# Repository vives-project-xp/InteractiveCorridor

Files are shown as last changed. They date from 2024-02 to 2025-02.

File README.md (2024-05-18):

# Interactive Corridor

Welcome to the Interactive Corridor Project! This unique corridor is designed to create depth and atmosphere through innovative lighting effects. With a variety of pre-programmed light patterns and the ability to design your own, you can transform the corridor into a dynamic and immersive space.

Controlling the effects is simple, just use the web interface hosted on a central server to customize the lighting. Whether you're aiming for subtle transitions or dramatic transformations, the Interactive Corridor Project gives you the tools to set the perfect mood. Enjoy exploring the endless possibilities!

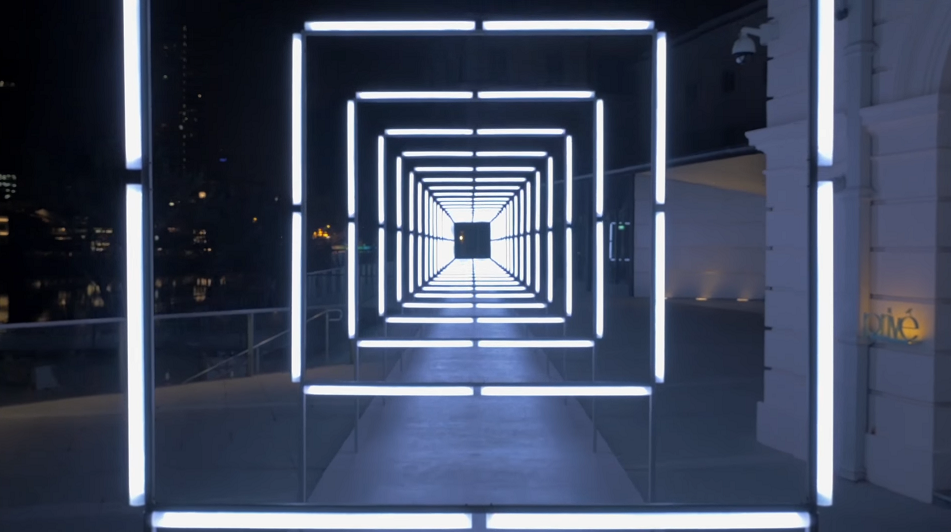
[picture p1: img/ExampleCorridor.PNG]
ExampleCorridor

The project is based on a video of the River Nights Festival (Singapore) where there was a beautiful light setup.
<https://www.youtube.com/watch?v=xEEKBbKvuMQ>

## The Team

[ Robbe De Wispelaere](https://github.com/RobbeDeW)

[ Aitor Vannevel](https://github.com/imawizzard)

[ Simon Stijnen](https://github.com/SimonStnn)

[ Niels Denoo](https://github.com/NielsDenoo)

## The idea

- **Dynamic Light Patterns** : Create customizable lighting sequences that can change in intensity, color, and direction to generate a sense of movement and depth within the corridor.
- **User-Friendly Web Interface**: Design an intuitive web page where users can easily control and customize the corridor's lighting effects. The interface should allow for real-time adjustments, offer a library of pre-set themes, and provide options to create and save custom patterns for future use.
- **MQTT Communication**: Use MQTT (Message Queuing Telemetry Transport) to send commands from the web interface to the LED strips. This lightweight messaging protocol ensures fast and reliable communication, allowing for seamless updates to the light patterns.
- **WLED Integration**: Implement WLED, an open-source control system for LED strips, to manage the lighting effects in the corridor. WLED allows for a wide range of customization options and can be controlled remotely, making it a perfect fit for this project.

## Folder Structure

- [Website](website/README.md): All information about how the website works and how the user can interact with it.
- [Backend](Backend/README.md) All information about how the website communicates with the ledstip's.
- [Docs](docs/README.md): All information about the hardware and setup

## Corridor data flow diagram

<picture>
  <source
    srcset="docs/exports/SoftwareArchitectureDiagram_dark.svg"
    media="(prefers-color-scheme: dark)"
  />
  <source
    srcset="docs/exports/SoftwareArchitectureDiagram_light.svg"
    media="(prefers-color-scheme: light), (prefers-color-scheme: no-preference)"
  />
  
</picture>

### Input requirements

The input requirements for the project are:

- The user should be able to control the LED strips via a web interface.
- The user should be able to change the color and brightness of the LED strips.
- The user should be able to select different lighting effects and animations for the LED strips.

### Functional requirements

The functional requirements for the project are:

- The system should provide a web interface for the user to control the LED strips.
- The system should provide an API for the web interface to communicate with the server.
- The server should listen to the API and control the ESP32s via the [WLED MQTT interface](https://kno.wled.ge/interfaces/mqtt/).
- The system should provide a user-friendly interface to adjust the color, brightness, and lighting effects of the LED strips.
- The system should provide a variety of lighting effects and animations for the user to choose from.
- The system should be able to handle multiple ESP32s.
- The system should be able to handle multiple users controlling the LED strips simultaneously.

### Output requirements

The output requirements for the project are:

- No flickering or lag in the LED strips.
- Reaction time is below 100ms.

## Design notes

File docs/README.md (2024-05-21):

# Documentation

Welcome to the documentation page! This is your go-to resource for understanding everything about our hardware system, including a detailed breakdown of the components we use. Whether you're building your own setup or simply exploring the technology, this page aims to provide all the information you need.

## Table of contents

- [Documentation](#documentation)
  - [Table of contents](#table-of-contents)
  - [Installation](#installation)
  - [Bill of Materials](#bill-of-materials)
  - [Level shifter](#level-shifter)
  - [Architecture documents](#architecture-documents)
    - [Hardware architecture diagram](#hardware-architecture-diagram)
    - [Wiring architecture diagram](#wiring-architecture-diagram)
    - [Wiring for Level shifter](#wiring-for-level-shifter)
  - [ESP Pinout](#esp-pinout)
  - [Measurements](#measurements)

## Installation

The installation of the hardware is quite simple. You can follow the steps below to install the hardware system:

1. **Mount the ledstrips**: Mount the ledstrips on the pillars. Mounting can be found in [mounting](./mounting/). You will also learn more about the process.
2. **Setup the ESP**: Setup the ESP32-C3. Installation steps can be found [here](./ESP_SETUP.md).
3. **Run the backend**: Run the backend. Installation steps can be found [here](../Backend/README.md#installation).

## Bill of Materials

These are the components that we purchased. You of course have different websites to purchase this, but we mainly looked at the price and quality of the product.

The Bill of Materials (BOM) lists all the components, parts, and materials needed for one corridor consisting of 6 pillars:

| Component | Quantity | Price / unit |
| :--- | :---: | ---: |
| [**ws2814-rgbw-led-strip**](https://www.btf-lighting.com/products/ws2814-12v-24v-4-in-1-similar-sk6812-rgbw-pixels-addressable-ws2811-rgbww-rgbcw-5050-3pin-led-lights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) | 6 | €22,35 |
| [**esp32-c3**](https://www.digikey.be/en/products/detail/espressif-systems/ESP32-C3-DEVKITM-1/13684315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) | 6 | €8,8451 |
| [**ledstrip-profile**](https://www.ledshop-groenovatie.com/Aluminium-Profiel-LED-Strip-Opbouw-1,5m-Compleet-1) | 16 | €17,95 |
| [**dcdc-converter**](https://www.otronic.nl/nl/lm2596s-instelbare-step-down-4-40v-125-37v-met-onb.html) | 6 | €5,39 |
| [**prototype-printplate**](https://www.otronic.nl/nl/experimenteer-prototyping-printplaat-7x9cm-groen.html) | 6 | €1,25 |
| [**cable-box**](https://www.allekabels.be/lasdoos/22371/3914218/aansluitdoos.html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) | 6 | €1,59 |
| [**power-supply**](https://www.ledstripkoning.be/accessoires/adapters-12-en-24-volt/600w-24v-25a-professionele-voeding-voor-led-strips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) | 1 | €76,95 |
| [**block-terminal**](https://be.farnell.com/camdenboss/ctb0100-6/pcb-terminal-5mm-6p/dp/3378876) | 6 | €2,12 |
| [**fuse-holder**](https://www.allekabels.be/zekeringen/1615/5715/standaard-zekeringhouder.html?lang=nl-be) | 3 | €4,22 |
| [**autofuse-set-10a**](https://www.allekabels.be/zekeringen/1615/1067905/mini-autozekering-10-ampere.html) | 1 | €5,29 |
| [**cables**](https://netstore.rexel.be/NS/servlet/be.rex.ns.cf.RexStartServlet?sessionreset=1) | 1 | €36,30 |
| [**female-pin-header-set**](https://be.farnell.com/en-BE/harwin/m20-7822046/connector-receptacle-tht-2-54mm/dp/7991967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) | 10 | €19,8 |
| [**Male-pin-header-set**](https://be.farnell.com/harwin/m20-9990846/connector-header-tht-2-54mm-8way/dp/1022257) | 10 | €3,52 |
| [**Lusterklemmen**](https://www.hubo.be/nl/p/profile-lusterklem-6mm-pvc-4-stuks/98445/) | 1 | €4,59 |

## Level shifter

| Component | Quantity | Price / unit |
| :--- | :---: | ---: |
| [**Resistor1K**](https://www.otronic.nl/nl/10x-weerstand-1k-ohm-1-4-watt-5.html) | 5 | €0,49 |
| [**Resistor1,5K**](https://www.kiwi-electronics.com/nl/weerstand-1-5k-ohm-1-4-watt-5-10-stuks-657) | 2 | €1,00 |
| [**transistor**](https://be.farnell.com/on-semiconductor/bc547ctfr/transistor-bipol-npn-45v-to-92/dp/2453792?st=BC547CTFR) | 24 | €6,312 |
| [**capacity1nF**](https://gigatek.be/nl/velleman-keramische-condensator-1nf--velvec1n0) | 24 | €0,08 |

## Architecture documents

### Hardware architecture diagram

<picture>
  <source
    srcset="./exports/HardwareArchitectureDiagram_dark.svg"
    media="(prefers-color-scheme: dark)"
  />
  <source
    srcset="./exports/HardwareArchitectureDiagram_light.svg"
    media="(prefers-color-scheme: light), (prefers-color-scheme: no-preference)"
  />
  
</picture>

The [architecture diagram](./ArchitectureDiagram.drawio) can be visualized in [app.diagrams.net](https://app.diagrams.net/) or with the [Draw.io Integration](https://marketplace.visualstudio.com/items?itemName=hediet.vscode-drawio) vscode extension.

If we look at the datasheets of all components, we need 2 different voltages.

- 24V for the ledstip
- 5V for the data and esp

### Wiring architecture diagram

<picture>
  <source
    srcset="./exports/Wiring-Wiring.drawio_Dark.svg"
    media="(prefers-color-scheme: dark)"
  />
  <source
    srcset="./exports/Wiring-Wiring.drawio_Light.svg"
    media="(prefers-color-scheme: light), (prefers-color-scheme: no-preference)"
  />
  
</picture>

### Wiring for Level shifter

<picture>
  <source
    srcset="./exports/Wiring-Level-Shifter.drawio_Dark.svg"
    media="(prefers-color-scheme: dark)"
  />
  <source
    srcset="./exports/Wiring-Level-Shifter.drawio_Light.svg"
    media="(prefers-color-scheme: light), (prefers-color-scheme: no-preference)"
  />
  
</picture>

The [architecture diagram](./ArchitectureDiagram.drawio) can be visualized in [app.diagrams.net](https://app.diagrams.net/) or with the [Draw.io Integration](https://marketplace.visualstudio.com/items?itemName=hediet.vscode-drawio) vscode extension.

## ESP Pinout

|  Pin  | Description |
| :---: | --- |
| GPIO1 | Ledstrip 1  |
| GPIO3 | Ledstrip 2  |

## Measurements

We have scope images of the level shifter, illustrating how the ESP (depicted in yellow) sends a 3.3V data signal. As it traverses the level shifter (represented by the blue signal), it is boosted to 5V. The green signal, measured at the collector of the first transistor, demonstrates signal inversion, necessitating the use of a second transistor.

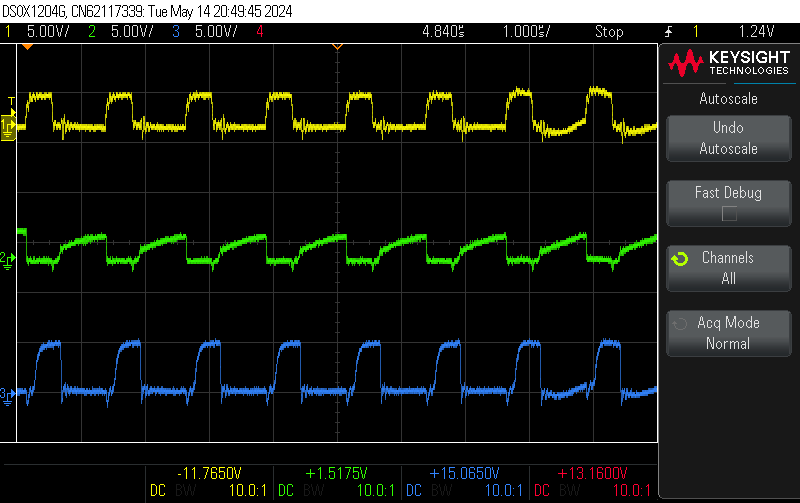
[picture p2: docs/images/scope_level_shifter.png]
Level Shifter


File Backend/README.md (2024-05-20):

# Backend

The backend is responsible for managing the ledstrips and the MQTT communication. It is implemented in JavaScript using [Node.js](https://nodejs.org/) and the [Express framework](https://expressjs.com/).

If you want to know more about the backend requests, click [here](http://10.11.0.100:9002/api-docs/). This link takes you to a swagger page where everything is explained.You must be connected to the Devbit network for this.

## Setup

First clone the repository:

```bash
git clone https://github.com/vives-project-xp/InteractiveCorridor.git
```

Setup your environment variables:

```bash
cp .env-example .env
```

Fill in the environment variables in the `.env` file.

Start the backend:

```bash
docker-compose up -d
```

The backend is now served on the URL specified in the `.env` file.

## UML Diagrams

```mermaid
classDiagram

class Segment {
    -start: number
    -end: number
    -color: Color
    -effect: Effect
    +constructor(parent: VirtualLedstrip, start: number, end: number, color: Color)
    +get length(): number
    +getHex(): string
    +setStart(start: number)
    +setEnd(end: number)
    +setColor(color: Color)
}

class Color {
    <<interface>>
    +r: number
    +g: number
    +b: number
}

class Effect {
    <<interface>>
    +id: number,
    +delay: number,
    +speed: number,
    +intensity: number,
    +reverse: bool,
    +mirror: bool,
}

class VirtualLedstrip{
    -_name: string
    -_segments: Segment[]
    +index: number
    +mqtt_enabled: boolean
    +get name: string
    +get segments: Segment[]
    +get length: number
    +constructor(name: string, index: number, segments: number[], mqtt_enabled: boolean)
}

VirtualLedstrip "1" *--o "1.." Segment
Color "1.." --* Segment
Effect "1.." --* Segment
```

## Virtual Ledstrip

The Virtual Ledstrip is a class that represents a ledstrip. It has a name, an index, a list of segments and a flag to enable or disable the MQTT communication.

### Constructor

The constructor of the Virtual Ledstrip class receives the following parameters:

- `name`: The name of the ledstrip.
- `index`: The index of the ledstrip.
- `segments`: An array of numbers representing the segments of the ledstrip.
- `mqtt_enabled`: A boolean flag to enable or disable the MQTT communication.

### Attributes

- `_name`: The name of the ledstrip.
- `_segments`: An array of segments.
- `index`: The index of the ledstrip.
- `mqtt_enabled`: A boolean flag to enable or disable the MQTT communication.

### Properties

- `name`: The name of the ledstrip.
- `segments`: An array of segments.
- `length`: The length of the ledstrip.

### Methods

The Virtual Ledstrip class has no methods.

## Segment

The Segment class represents a segment of a ledstrip. It has a start, an end and a color.

### Constructor

The constructor of the Segment class receives the following parameters:

- `start`: The start of the segment.
- `end`: The end of the segment.
- `color`: The color of the segment.

### Attributes

- `start`: The start of the segment.
- `end`: The end of the segment.
- `color`: The color of the segment.

### Properties

- `length`: The length of the segment.

### Methods

- `getHex()`: Returns the color of the segment in hexadecimal format.
- `setStart(start)`: Sets the start of the segment.
- `setEnd(end)`: Sets the end of the segment.
- `setColor(color)`: Sets the color of the segment.

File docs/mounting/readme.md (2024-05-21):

# SETUP

> Ensure a well-organized setup where the LED strips are securely fastened and everything is neatly concealed.

### Discussion with Technical Service (21/02/24)

The technical service is considering providing power in the cable tray that crosses corridor B. We will provide an adapter that converts 220V to 24V. This will be installed in room B303, in the ceiling near the projector. The technical service will install a cable tray at the top of the corridor up to the first concrete pillar. We will supply aluminum brackets for the LED strip, which the technical service will then attach (drilling/adhesion).

We will handle the finishing touches:

- Box for the ESPs
- Brackets for the LED strips
- Wiring concealment

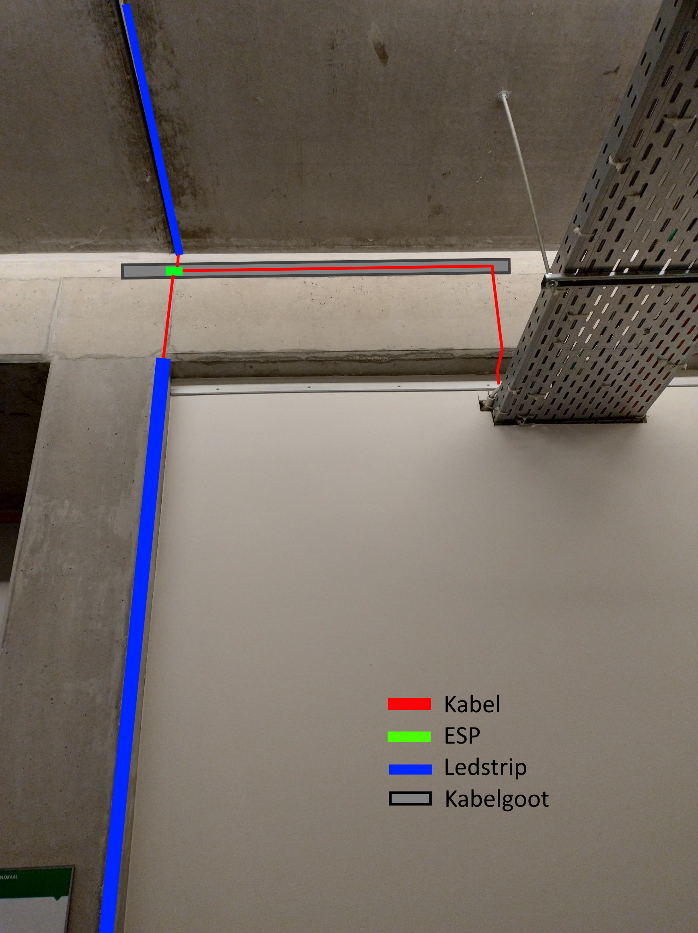
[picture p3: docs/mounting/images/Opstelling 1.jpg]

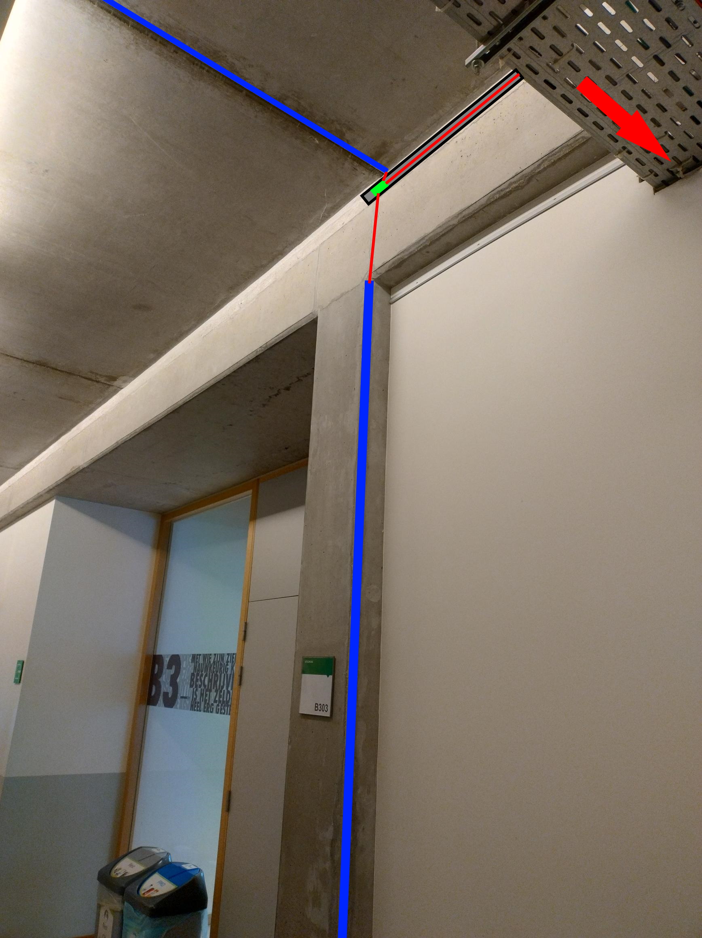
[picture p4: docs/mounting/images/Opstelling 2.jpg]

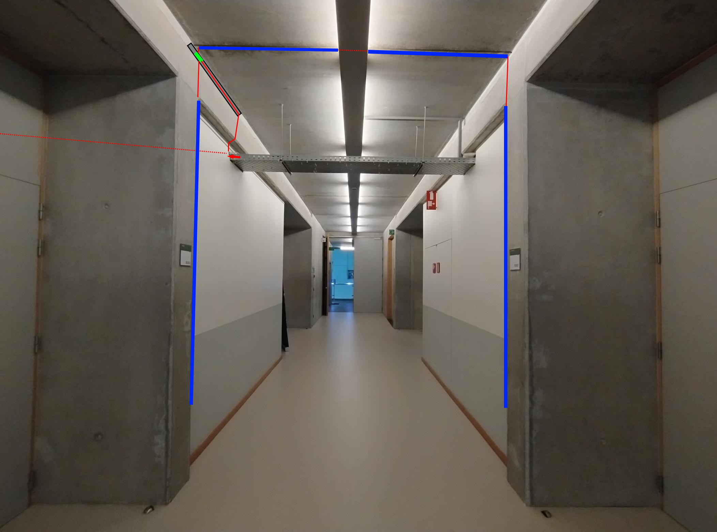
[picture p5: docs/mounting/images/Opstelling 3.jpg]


### First Corridor (22/04/2024)
To reduce costs, we have shortened the length of the defusers on the wall and they are now all 1m.

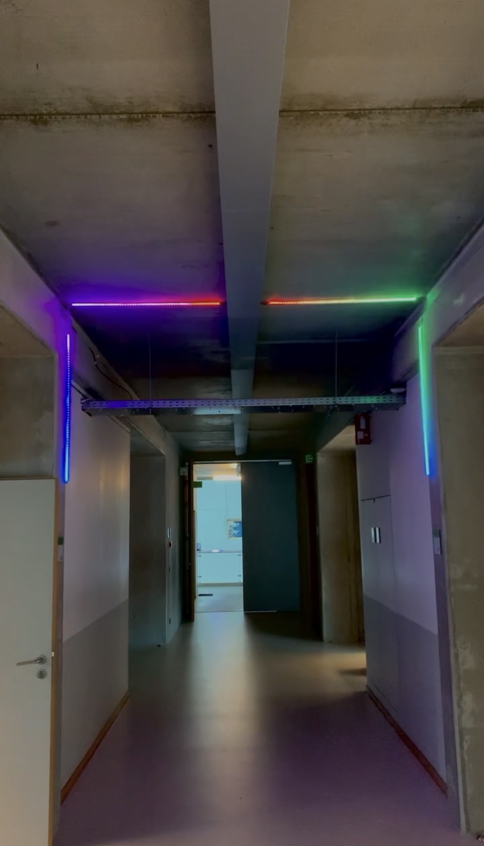
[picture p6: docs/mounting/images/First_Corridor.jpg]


### Final Result (14/05/2024)
This is the complete setup that you can control and we are very proud of this.😊

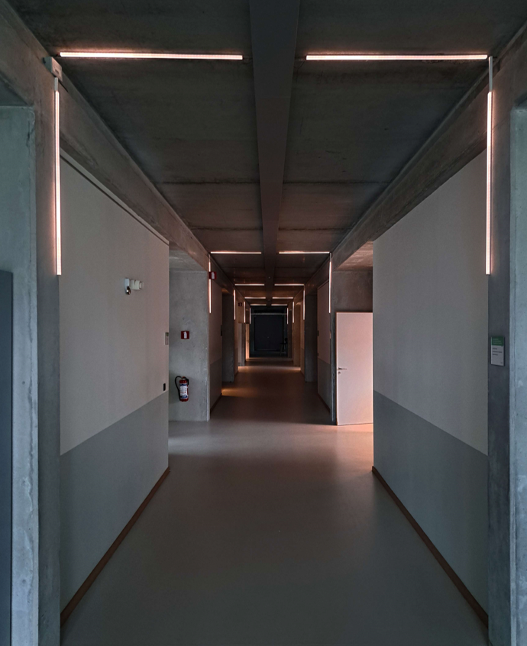
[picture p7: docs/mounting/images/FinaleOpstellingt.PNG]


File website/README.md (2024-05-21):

# Welcome to the "Website" page

This website is utilized to manage all corridors, thereby creating stunning effects in the hallway. [Website](http://10.11.0.100:9002/api-docs/) You must be connected to the Devbit network to access the website or you can do this yourself via Docker Desktop.

## Technologies used

- [Axios-HTTP](https://axios-http.com/): a promise based HTTP client for the browser and node.js
- [Tailwind CSS](https://tailwindcss.com/): a utility-first CSS framework
- [Shadcn-vue](https://www.shadcn-vue.com/): a component library for vue
- [Vue.js](https://vuejs.org/): a JavaScript framework for building user interfaces
- [Docker](https://www.docker.com/): a platform for building, shipping, and running applications in containers

## Home page

The main page serves as the central hub for customizing the aesthetic appeal of your corridors. It offers a user-friendly interface to effortlessly alter the colors of different segments according to your preferences. Each segment can be individually tailored with just a click. Simply choose the segment you wish to modify, and watch it transform before your eyes as you select your preferred color scheme.

But customization doesn't stop there. Want to create a more dynamic layout? With the "split" button, you can easily divide the corridor into smaller sections, providing greater flexibility in design. Whether you prefer a uniform look or a segmented display, this feature empowers you to configure your space exactly as you envision it.

To streamline the customization process even further, the "all" option enables you to select the entire corridor at once. This eliminates the need to manually click on each segment, saving you time and effort. Whether you're fine-tuning the details or making sweeping changes, the main page offers intuitive tools to bring your corridor design to life with precision and ease

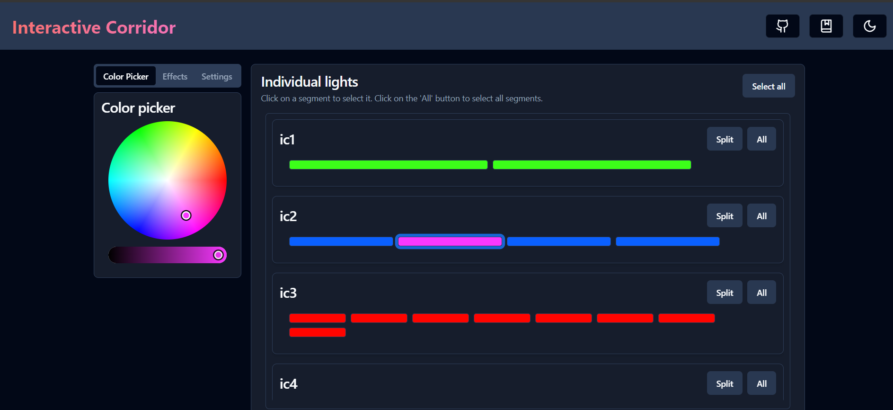
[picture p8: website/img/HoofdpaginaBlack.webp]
Home Page


## Effect page

### WLED effects

The effect page serves as a hub for enhancing the ambiance of your corridor with captivating visual effects. Similar to the color customization process, adjusting effects is seamless and intuitive. Simply select the segment or segments you wish to modify, and then choose from a diverse array of effects. From subtle pulsations to vibrant rainbows and beyond, there's a wide selection to suit every mood and theme.

What's exciting about these effects is their dynamic nature. Unlike color changes, the effects won't immediately manifest on your website interface. Instead, you'll need to hover over the segment to see what te effect is on that segment.

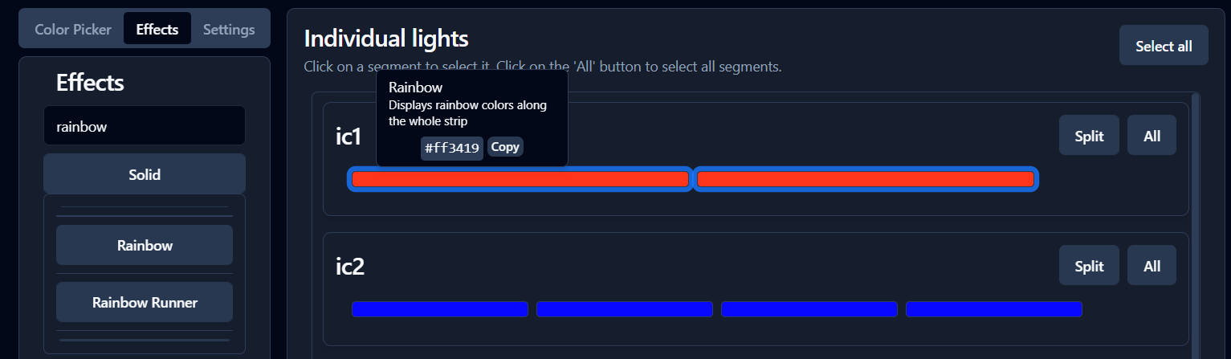
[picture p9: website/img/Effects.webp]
Effect page


### Own effects

Unlock your creativity by crafting and saving your own unique effects to imbue your corridors with a personalized touch. Whether it's experimenting with vibrant colors or layering mesmerizing effects, the possibilities are endless. Once you've perfected your creation, simply assign it a distinct name and save it for future use.

Choosing a descriptive and exclusive name for your custom effect is essential, as duplicate names are not permitted. This ensures that each effect in your repertoire is easily identifiable and avoids confusion when managing your collection. By meticulously naming your effects, you pave the way for seamless organization and effortless access to your favorite creations.

The ability to save custom effects streamlines your workflow, allowing you to effortlessly apply and replay intricate designs without starting from scratch each time. Whether you're refining existing effects or inventing entirely new ones, this feature empowers you to curate a library of personalized enhancements tailored to your unique vision.

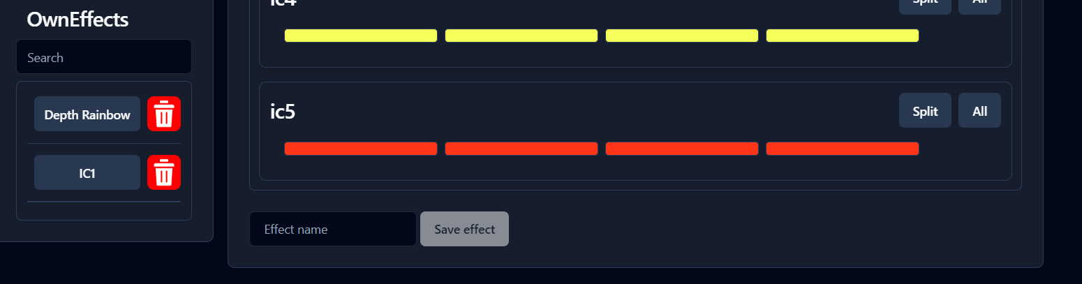
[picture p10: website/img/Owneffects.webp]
Own effects


## Settings page

- **Speed**: When you change the speed of an effect, the playback speed will be faster or slower.
- **Intensity**: Specifically, the "Intensity" setting adjusts the density or frequency of the effect applied to the LED strip.
- **Delay**: By adjusting the delay you will create a delay between 2 or more corridors so that, for example, they will turn on alternately with the blink effect.
- **Reverse Delay**: If you want the delay to work in a mirrored order, click this button (instead of the last corridor turning on first, the first corridor will turn on first and then the rest).
- **Mirror**: When you select the "Mirrored" option, each corridor will display the effect in a mirrored fashion.
- **Reverse**: When you press this button the effect will be played in reverse, although your effect runs from left to right by default, it will now be reversed.

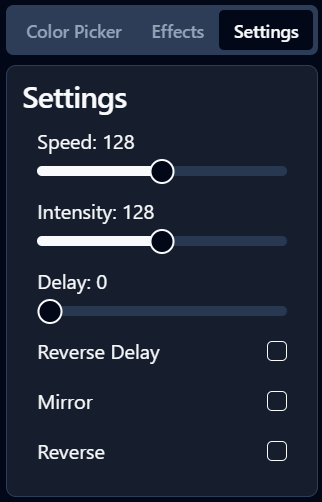
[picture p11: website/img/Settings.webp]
Settings


## Some extra's

As an added bonus, we've incorporated a delightful feature that allows you to effortlessly switch between light and dark themes for your website. Simply look to the top right corner of your screen, where you'll find an inviting sun and moon icon. By clicking on these icons, you can seamlessly transition between the two themes, catering to your preferred browsing experience.

Of course we have set dark theme as default 😉

You can also go to our GitHub page and documentation page when you press the buttons at the top right of the screen.

but here is an example of the white theme:
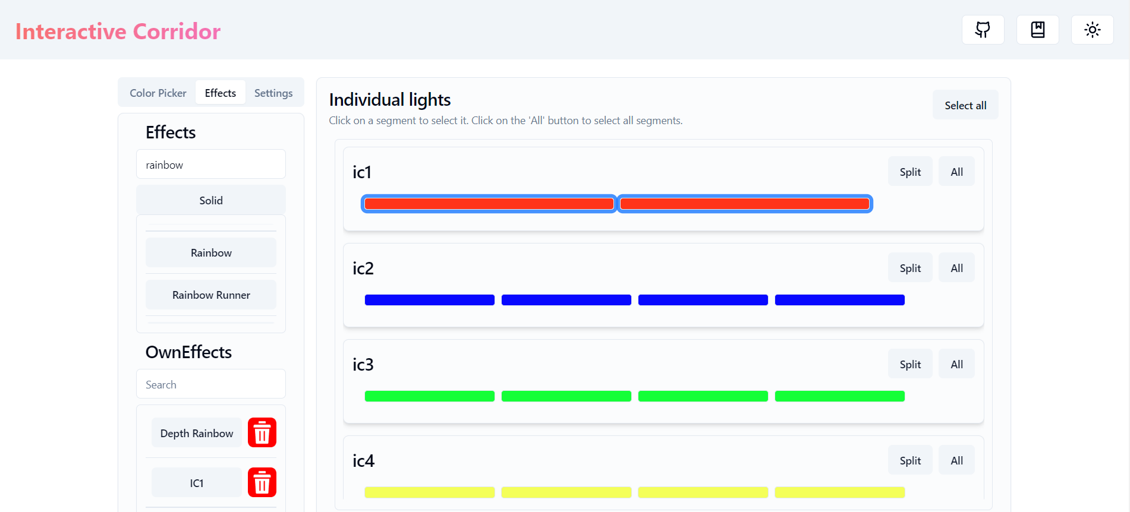
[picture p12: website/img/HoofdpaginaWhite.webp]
White team


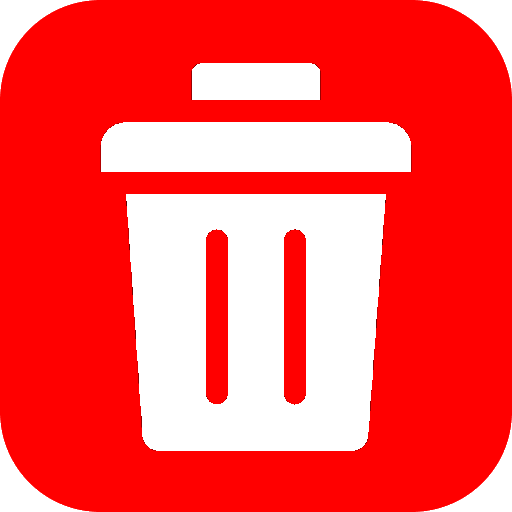
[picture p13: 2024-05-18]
website/img/delete.png

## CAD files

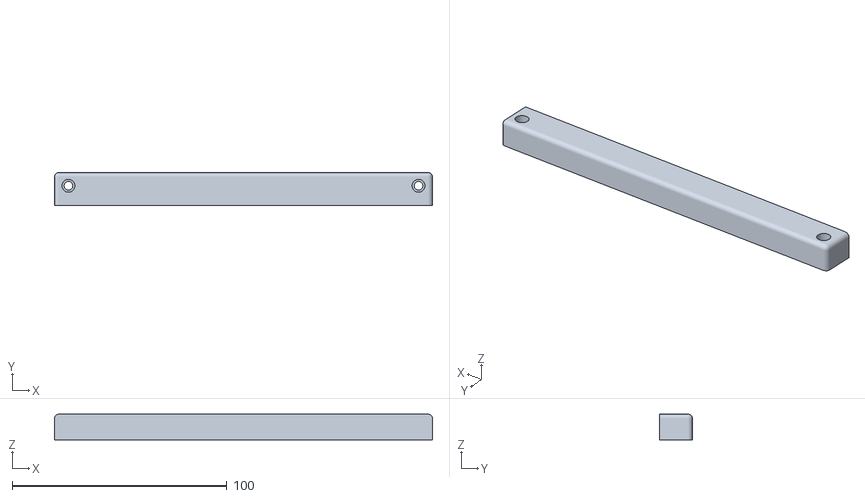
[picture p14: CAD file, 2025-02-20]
3dprints/SamsungTabA6Deksel.stl
176.0 x 15.3 x 12.0

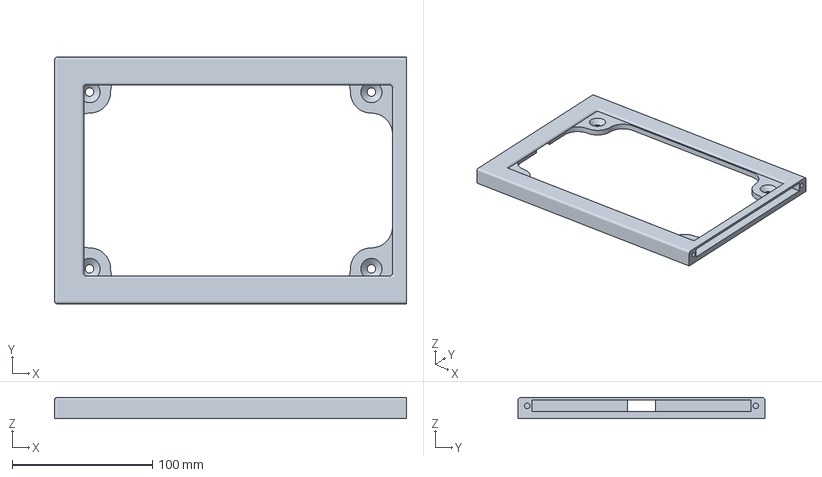
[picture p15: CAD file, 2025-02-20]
3dprints/SamsungTabA6.3mf
251.0 x 176.0 x 15.3 mm

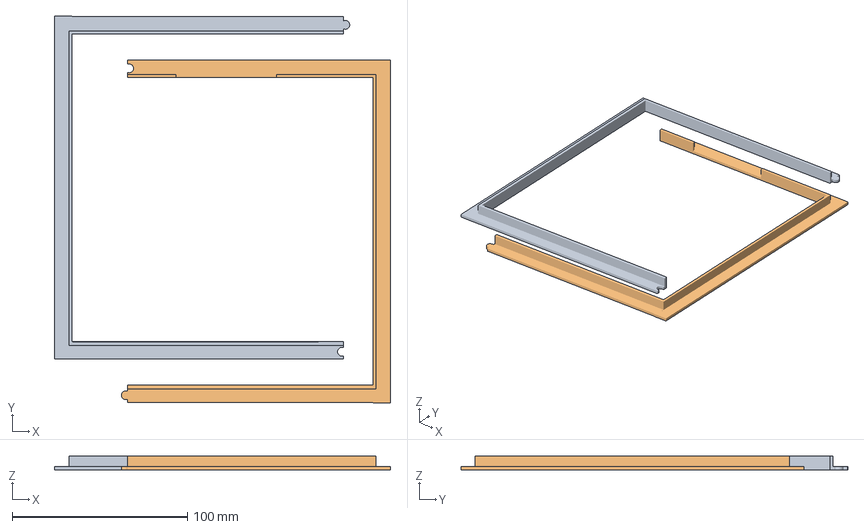
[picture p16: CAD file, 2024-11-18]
3dprints/SM-T580-Wandhalter_v2.3mf
191.6 x 220.6 x 8.26 mm
SM-T580-Abdeckungshalter.stl_1
SM-T580-Abdeckungshalter.stl_2

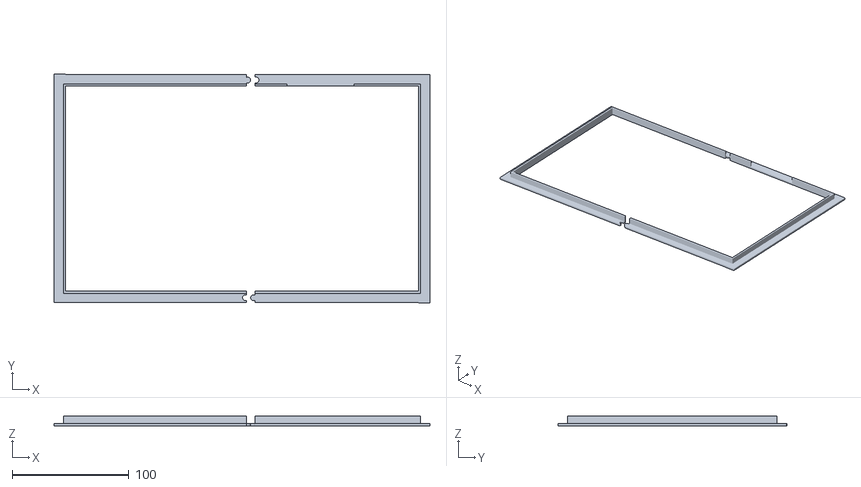
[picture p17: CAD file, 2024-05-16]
3dprints/SM-T580-Abdeckungshalter.stl
321.9 x 195.8 x 8.26

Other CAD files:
3dprints/SM-T580-Wandhalter_v2.stl
3dprints/SamsungTabA6.stl

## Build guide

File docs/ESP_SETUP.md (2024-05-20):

# Installing WLED on your ESP32

## Instructions

1. [Install WLED](#1-install-wled)
2. [Upload config file](#2-upload-config-file)
   - [2.1 Download the config file](#21-download-the-config-file)
   - [2.2 Upload the config file](#22-upload-the-config-file)
     - [2.2.1 Open the settings in WLED](#221-open-the-settings-in-wled)
     - [2.2.2 Open "Security & Updates"](#222-open-security--updates)
     - [2.2.3 Upload the config file](#223-upload-the-config-file)
3. [Reboot WLED](#3-reboot-wled)
4. [Setup MQTT](#4-setup-mqtt)
   - [4.1 Open the config](#41-open-the-config)
   - [4.2 Open Sync Interfaces](#42-open-sync-interfaces)
   - [4.3 Change settings](#43-change-settings)
   - [4.4 Reboot WLED](#44-reboot-wled)

## 1. Install wled

> Follow the instructions on the wled site to install wled on your device.

### **[Wled](https://install.wled.me/)**

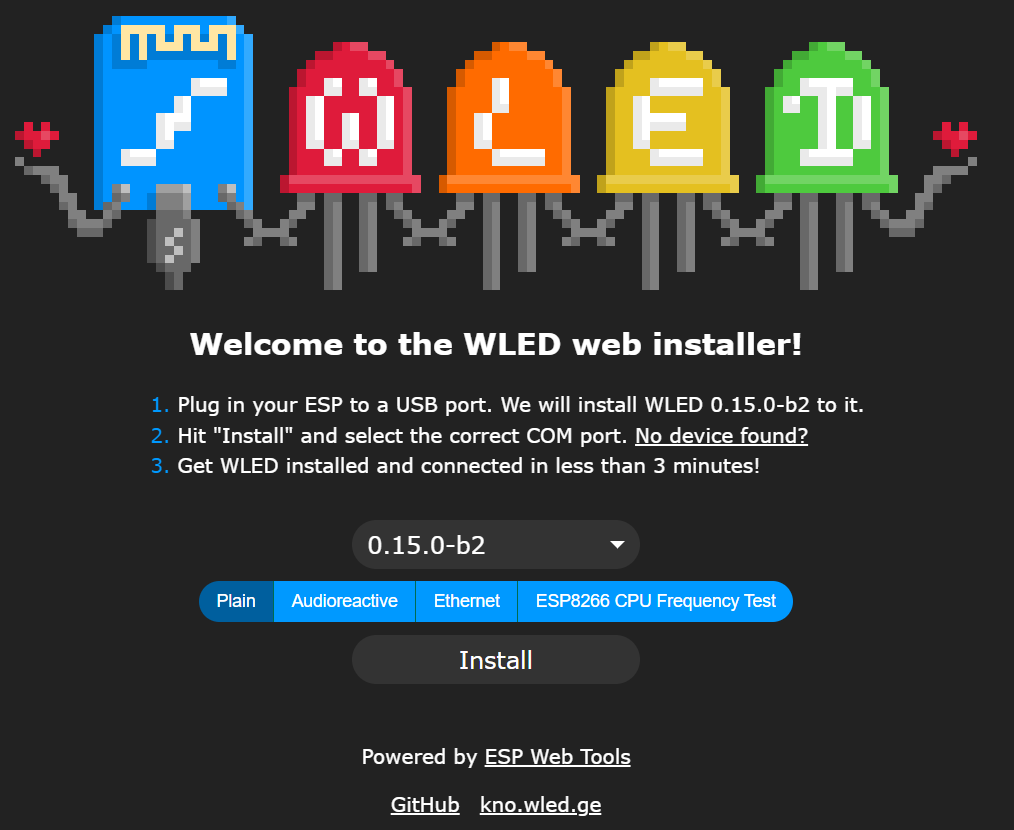
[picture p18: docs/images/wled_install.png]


## 2. Upload config file

### 2.1 Download the config file

You can download the config file <u>**[HERE](../wled_cfg.json)**</u>.

### 2.2 Upload the config file

> 2.2.1 Open the settings in wled.

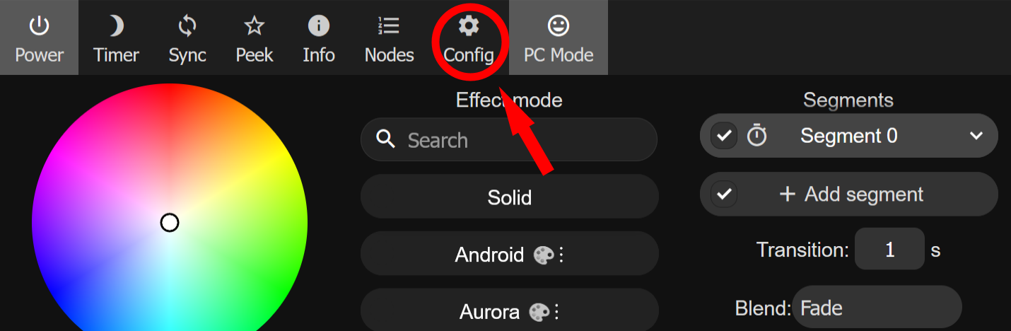
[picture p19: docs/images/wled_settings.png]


<br>
<br>

> 2.2.2 Open "Security & Updates".

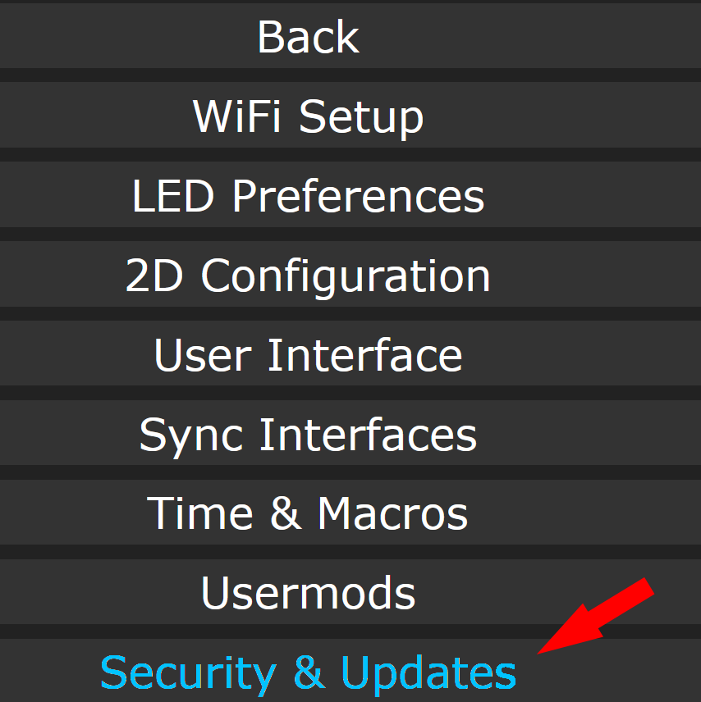
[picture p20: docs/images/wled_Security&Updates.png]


<br>
<br>

> 2.2.3 Upload the config file.

_Don't forget the save after upload!_
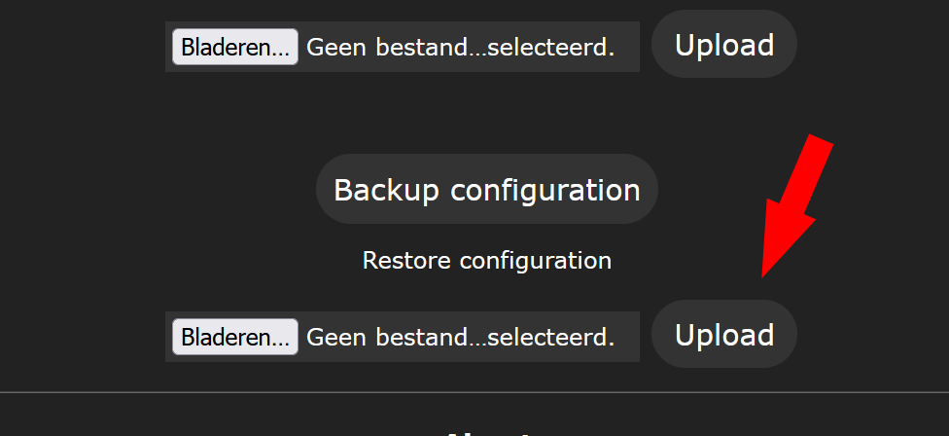
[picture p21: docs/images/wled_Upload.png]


## 3. Reboot wled

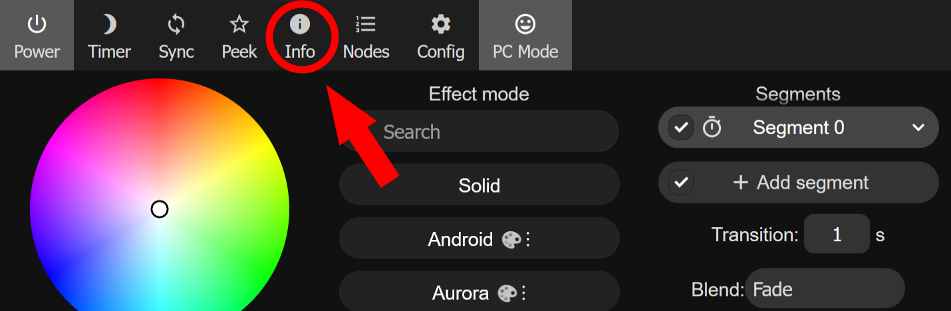
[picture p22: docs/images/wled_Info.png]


<br>

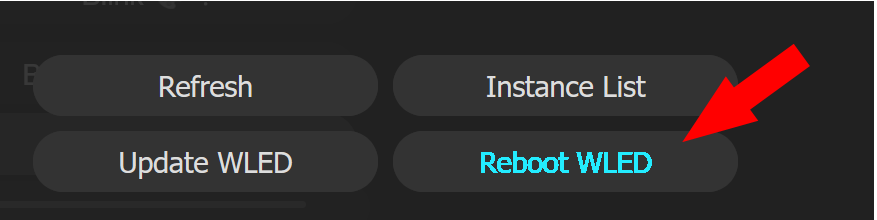
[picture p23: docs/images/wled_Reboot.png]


## 4. Setup mqtt

### 4.1 Open the config



### 4.2 Open Sync Interfaces

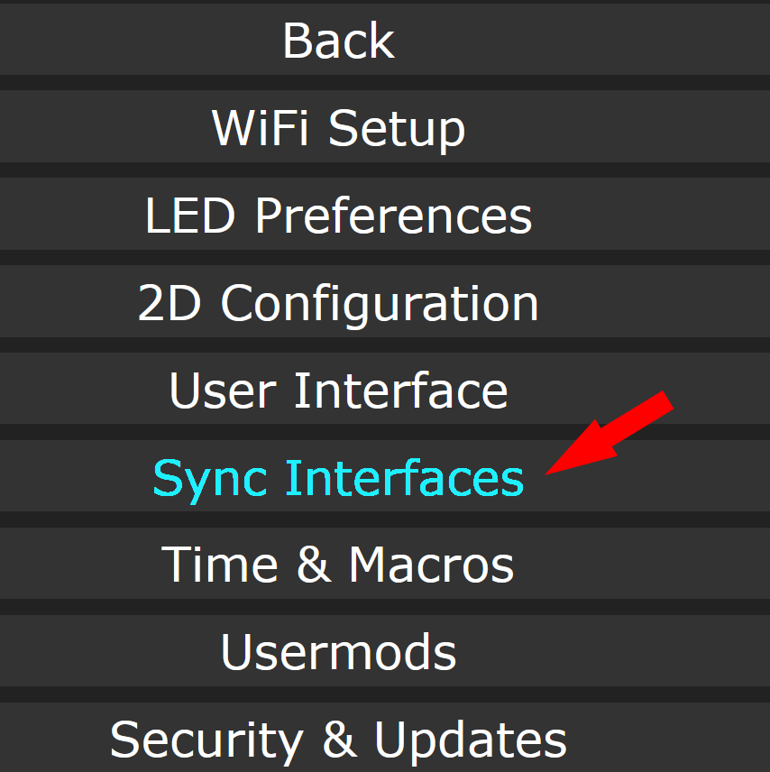
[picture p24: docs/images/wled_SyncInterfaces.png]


### 4.3 Change settings

> Fill in your broker url and login.
> Device & group topic is the topic you entered in the env file

#### **AFTER YOUR TOPIC, YOU NEED TO ADD /ic[LED_NUMBER]**

#### **THE GROUP TOPIC SHOULD END WITH /ALL**

_Don't forget the save after changing the settings!_

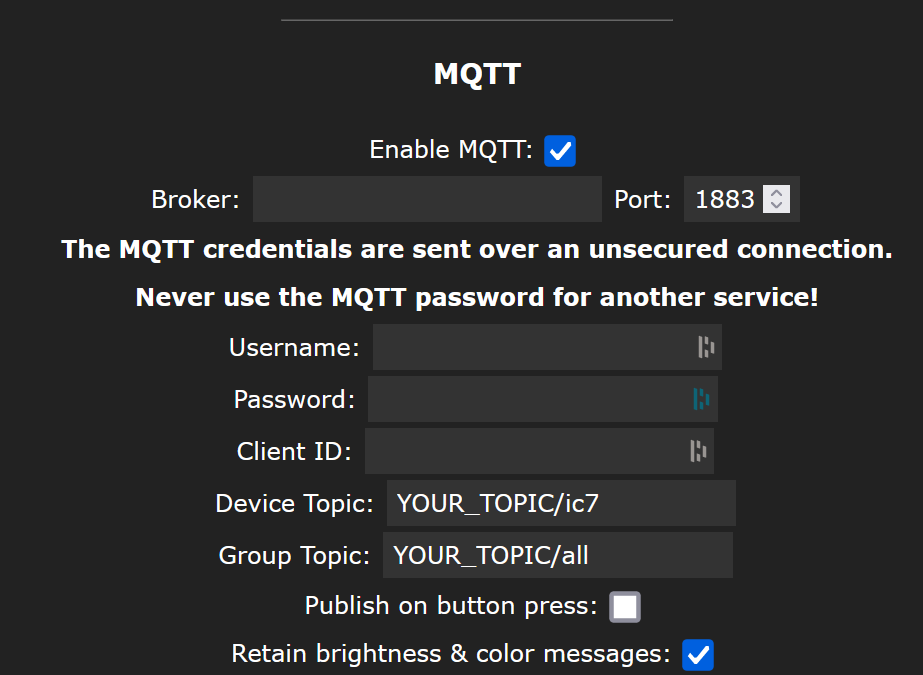
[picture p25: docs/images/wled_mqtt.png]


### 4.4 Reboot wled

Reboot wled one more time to load all the settings (see [3.Reboot wled](#3-reboot-wled)).

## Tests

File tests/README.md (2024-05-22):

# Tests

## Software

A list of tests that should be performed on the software. The software should be tested for the following:

<details>
<summary>Ease of use</summary>

- [x] An enduser should be able to use the software without any prior knowledge
  - [x] An enduser should be able to look and the website and know how to controll the ledstrips
  - [x] An enduser should be able to look at the website and know how to change the settings
  - [x] An enduser should be able to look at the website and know how to change the color of the ledstrips
  - [x] An enduser should be able to look at the website and know how to change the brightness of the ledstrips
  - [x] An enduser should be able to look at the website and know how to change the speed of the ledstrips
  - [x] An enduser should be able to look at the website and know how to change the mode of the ledstrips
  - [x] An enduser should be able to look at the website and know how to change the direction of the ledstrips
  - [x] An enduser should be able to look at the website and know how to split a ledstrip in multiple segments
  - [x] An enduser should be able to look at the website and know how to change the color of a segment
  - [x] An enduser should be able to look at the website and know how to change the color of a whole ledstrip
- [x] The software should be easy to install
  - [x] An step by step installation guide should be available
  - [x] Someone with basic knowledge of computers should be able to install the software
  - [x] After setting up the config files the software should be able to start with one command
- [x] The software should be easy to configure
  - [x] A step by step configuration guide should be available with with files to edit and what to edit

</details>

<details>
<summary>Documentation</summary>

- [x] The website should have a README.md file
  - [x] The README.md file should contain a description of the software
  - [x] The README.md file should contain the technologies used
  - [x] The README.md file should contain some screenshots of the website
- [x] The backend should have a README.md file
  - [x] The README.md file should contain a description of the software
  - [x] The README.md file should contain the technologies used
  - [x] The README.md file should contain an UML diagram of the Virtual Ledstrip
  - [x] The README.md file should contain documentation of the Virtual Ledstrip
- [x] There shoud be a docs folder with a README.md file
- [x] Swagger API docs
  - [x] The API should be documented with Swagger
  - [x] The Swagger docs should have the save paramters and responses as the API

</details>

## Hardware

<details>
<summary>Components</summary>

- [x] The converter should convert the 24V input into 5V output
- [x] The level shifter should be able to make the 3.3V signal into a 5V signal
- [x] The electrical supply should be able to power all the 5 ledstrips
- [x] Test the ledstrips
  - [x] Test the max current of the ledstrips
  - [x] Check the required voltage of the ledstrips
- [x] Test if the ESP sends a signal
- [x] Test if the ledstrips are working with the signal
  - [x] Check if the signal at the end is 5V
  - [x] Check if u get the right effect on the ledstrips
- [x] Test if everything works

</details>

<details>
<summary>Documentation</summary>

- [x] The signals of the hardware should be documented with scope images
- [x] The README.md file in docs should contain info about the used components
- [x] The README.md file in docs should contain both hardware and software architecture diagram
- [x] The README.md file in docs should contain wiring diagram and how the level-shifter is made

</details>

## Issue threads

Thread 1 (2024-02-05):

Meten hoogt een breedte gang

RobbeDeW, 2024-02-05:
De ledstips worden in de gang gehangen waardoor we de hoogte en de breedte van de gang moeten weten.

RobbeDeW, 2024-02-05:
Lengtes van de gang
Hoogt: 3.30m
Breedte: 2.40m

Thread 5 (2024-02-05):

Mail Sam Baldewijns

NielsDenoo, 2024-02-05:
Mail sturen naar Sam Baldewijns voor mogelijkheden elektriciteit voor ledstrips (eerst mail sturen naar meneer Leroy voor goedkeuring mail)

RobbeDeW, 2024-02-07:
Mail naar project begeleider verstuurt om te weten of het een goede mail was en we mogen afspreken met Sam.

RobbeDeW, 2024-02-19:
Mail naar Sam is verzonden.

RobbeDeW, 2024-02-19:
Er is een datum vastgelegd om af te spreken met Sam.

Closed 2024-02-19.

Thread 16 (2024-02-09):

General Product Architecture: Power

SimonStnn, 2024-02-09:
Describe how the ESP and LED strip will receive power in the docs.

SimonStnn, 2024-02-09:
## ESP32

ESP32 can be powered over USB with 5V or it can be powered via the pins with 3.3V as mentioned [here](https://docs.espressif.com/projects/esp-hardware-design-guidelines/en/latest/esp32c3/schematic-checklist.html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,no%20less%20than%20500%20mA.).

## LED strip

LED strip requires a 24V power supply

Closed 2024-03-04.

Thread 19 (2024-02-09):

Complete BOM table

SimonStnn, 2024-02-09:
Complete the table of the [BOM](https://github.com/vives-project-xp/InteractiveCorridor/tree/main/docs#bill-of-materials) with the components, items, materials, etc needed to build a corridor.

> This is the same list you made in #2

SimonStnn, 2024-02-09:
Install the [Markdown All in One](https://marketplace.visualstudio.com/items?itemName=yzhang.markdown-all-in-one) vscode extension so you can format the table when you want to commit (`Alt + Shift + F`).

Also install the [markdownlint](https://marketplace.visualstudio.com/items?itemName=DavidAnson.vscode-markdownlint) vscode extension. This will lint markdown files.

> Don't commit if you have warnings in the document 😉.

Closed 2024-02-27.

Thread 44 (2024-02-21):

Ontwerp website maken

RobbeDeW, 2024-02-21:
Een ontwerp maken voor de website. Dit wordt best eerst op papier in klad gedaan.
- Hoe ziet de website er uit
- Interactie met gebruiker en leds
- Pagina effecten, interactie,

SimonStnn, 2024-02-21:
Ontwerp kan met figma gemaakt worden. Die kunnen opgeslaan worden als .fig bestanden.

Closed 2024-02-28.

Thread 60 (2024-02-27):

Testen 24V Ledstip

RobbeDeW, 2024-02-27:
-Er worden metingen gedaan met deze ledstip
-Er wordt getest of de ledstip goed werkt

RobbeDeW, 2024-02-27:
Ledstip werkt zonder level shifter maar als we een level shifter gebruiken die in school aanwezig was werkt de ledstip niet meer.

imawizzard, 2024-03-11:
Met onze eigen levelshifter werken de ledstrips perfect. Er zijn geen verstoringen meer doordat de data nu op 5V wordt gestuurd.

Closed 2024-03-11.

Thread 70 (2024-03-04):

Issue when fetching ledstrips in server

SimonStnn, 2024-03-04:
When fetching the leds it fails and it responds it has found 0 strips.

Closed 2024-03-04.

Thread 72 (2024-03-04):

Warnings when creating leds on website

SimonStnn, 2024-03-04:
`undefined` gets passed in as a color, which is invalid.

```txt
Invalid prop: type check failed for prop "color". Expected String with value "undefined"
```

Closed 2024-03-04.

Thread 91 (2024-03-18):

Color picker color gets reset when switching tabs on website

SimonStnn, 2024-03-18:

Closed 2024-03-18.

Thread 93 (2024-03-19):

Something is wrong with the swagger ui version

SimonStnn, 2024-03-19:
Our current ui looks like this:
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

But it should look like this:
(example)
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

This propably has something to do with the version of swagger ui.

SimonStnn, 2024-03-19:
Problem can be fixed with [swagger-jsdoc](https://www.npmjs.com/package/swagger-jsdoc).

Closed 2024-03-19.

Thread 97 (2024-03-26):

Ledstrip section color gets reset after some delay

SimonStnn, 2024-03-26:

Closed 2024-03-30.

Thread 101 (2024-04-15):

Search secondary school to give the presentation

SimonStnn, 2024-04-15:
Go 21 april to KTA Brugge open day.

SimonStnn, 2024-04-15:
"Graag een selfie"

SimonStnn, 2024-04-22:
We mogen presentatie gaan geven, wel nog eens een mailtje sturen om verder af te spreken.

We can give a presentation, we can send an email to discuss further.

Closed 2024-04-22.

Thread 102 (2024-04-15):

Handle changing ledstrip effects

SimonStnn, 2024-04-15:
Send effects to the selected sections when clicking an effect

SimonStnn, 2024-04-16:
There is still an issue with updating the effect. (#108)

Closed 2024-04-16.

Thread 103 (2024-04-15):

Ledstip aan muur hangen

RobbeDeW, 2024-04-15:
We plakken met plakband de lestip aan de muur om te zien of dat er goed uit ziet en op welke manier we hem aan de muur zullen hangen.

RobbeDeW, 2024-04-16:
Het ziet er goed uit dus dit kan nu aan de muur worden gehangen

Closed 2024-04-16.

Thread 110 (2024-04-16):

Get own effect from database on website

RobbeDeW, 2024-04-16:
We halen alles effecten op vanuit de database en geven deze weer op de website inde vorm van een button. Als je of deze button drukt zou het effect moeten worden afgespeeld.

RobbeDeW, 2024-04-16:
Dit werkt je kunt je own effects zien op de website de knop werkt wel nog niet

Closed 2024-04-16.

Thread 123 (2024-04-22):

Kabel doortrekken

RobbeDeW, 2024-04-22:
We leggen een 2mm dikke kabel naar het lokaal om ons van stroom voorzien.

RobbeDeW, 2024-04-22:
De kabel is doorgetrokken en er kan nu vanuit het lokaal stoom genomen worden

Closed 2024-04-22.

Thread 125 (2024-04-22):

Ledstrip segmends don't get set by the server

SimonStnn, 2024-04-22:
The one segment preset doesn't get overridden when updating the strip

Closed 2024-04-23.

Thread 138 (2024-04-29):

Throttle the requests to change the effect

SimonStnn, 2024-04-29:
When setting the effect in the settings tab the requests should be throttled to prevent overloads.

Closed 2024-04-29.

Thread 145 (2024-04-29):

Fixing ledstip

RobbeDeW, 2024-04-29:
De ledstrip die niet werkt hersolderen

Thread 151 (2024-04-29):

Effect loading from db not correct

imawizzard, 2024-04-29:
The length of the segments are wrong when loading from the database

imawizzard, 2024-05-14:
Effect are now correct loading from the database.
Added delete button.

Closed 2024-05-14.

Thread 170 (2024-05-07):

Pop up name 'already exists' dB owneffects

RobbeDeW, 2024-05-07:
Als een gebruiker een nieuw effect wil opslaan en het een naam geeft, moet je ervoor zorgen dat deze naam niet al in de database voorkomt.

RobbeDeW, 2024-05-15:
Het pop up scherm werkt

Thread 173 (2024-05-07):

Error in ledstrip.vue

imawizzard, 2024-05-07:
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

imawizzard, 2024-05-07:
Wrong api call: /effect -> /effects

Closed 2024-05-07.

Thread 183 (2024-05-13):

Use permalink for effects

SimonStnn, 2024-05-13:
Change the source url for the effects to a permalink. If they change any of the effects our ledstrip will not break.

Use this link:
[`https://raw.githubusercontent.com/scottrbailey/WLED-Utils/ec0bad83b35358137569d4cc9a016e235e00ffed/effect_descriptions.json`](https://raw.githubusercontent.com/scottrbailey/WLED-Utils/ec0bad83b35358137569d4cc9a016e235e00ffed/effect_descriptions.json)

Replace the link here:
https://github.com/vives-project-xp/InteractiveCorridor/blob/13fde039942210312197d2efa013e76b2fd1a01d/Backend/src/effect.js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

Closed 2024-05-13.

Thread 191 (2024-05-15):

Write the website README

SimonStnn, 2024-05-15:
The README should contain the tests defined in the tests.

https://github.com/vives-project-xp/InteractiveCorridor/blob/cd700050d2d5e619b6452cdbe7e34032e2879e4b/tests/README.md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

RobbeDeW, 2024-05-15:
Alles over de hoe je de kleuren en over de effecten staat in de readme

Closed 2024-05-19.

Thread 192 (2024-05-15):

Presentatie updaten

RobbeDeW, 2024-05-15:
We hebben onze presentatie gedaan in de middelbare school deze moet nog worden geupdate voor onze eindpresentatie.

NielsDenoo, 2024-05-17:
Er is een sjabloon aangemaakt voor de presentatie die gebruikt moet worden voor de eindpresentatie

Closed 2024-05-22.

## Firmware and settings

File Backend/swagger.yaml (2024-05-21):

openapi: 3.0.8
info:
  title: Stripconfiguratie API
  description: API voor het configureren van LED-strips.
  version: 1.0.0
servers:
  - url: http://localhost/api
    description: Backend server # Beschrijving van de server

paths:
  /leds:
    get:
      summary: Get LED configurations
      responses:
        200:
          description: "Successful operation"
          content:
            application/json:
              schema:
                type: array
                items:
                  $ref: "#/components/schemas/Ledstrip"

    post:
      summary: Set LED configurations
      parameters:
        - in: query
          name: query
          required: true
          schema:
            type: array
            items:
              $ref: "#/components/schemas/Ledstrip"
      responses:
        200:
          description: LED configurations set successfully
  /changeled:
    post:
      summary: Change LED segments
      parameters:
        - in: query
          name: query
          required: true
          schema:
            type: object
            properties:
              strip:
                type: object
                properties:
                  index:
                    type: number
                    description: The index of the LED strip
      responses:
        200:
          description: LED segments changed successfully
  /effects:
    post:
      summary: Set effect for LED strips
      parameters:
        - in: query
          name: query
          required: true
          schema:
            type: object
            properties:
              strips:
                type: array
                items:
                  $ref: "#/components/schemas/Ledstrip"
              delay:
                type: number
                description: Delay for the effect
                minimum: 1
                maximum: 1000
                nullable: true
              effect:
                type: number
                description: ID of the effect
                example: 0
              intensity:
                type: number
                description: Intensity of the effect
                minimum: 1
                maximum: 255
                nullable: true
              mirror:
                type: boolean
                description: Mirror the effect
                nullable: true
              reverse:
                type: boolean
                description: Reverse the effect
                nullable: true
              reverseDelay:
                type: boolean
                description: Reverse the delay
                nullable: true
              speed:
                type: number
                description: Speed of the effect
                minimum: 1
                maximum: 255
                nullable: true
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

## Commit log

2024-02-05 Add hall dimensions to docs README.md
2024-02-05 Add server and ledstrip details to README.md
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2024-02-06 Move esp code from esp/LedControl/ to esp/
2024-02-07 created python script to sned mqtt messages to the ledstrips
2024-02-07 Add ESP32 and WLED software documentation
2024-02-09 Add power supply information for ESP32 and LED strips #16
2024-02-09 Add Bill of Materials template to README.md close #18
2024-02-10 Write WS2814 ledstrip interface documentation #17
2024-02-10 Update WS2814 LED strip information #17
2024-02-10 Update LED strip description #17
2024-02-10 Update WS2814 LED strip to WS2814 Protocol #17
2024-02-11 Remove unnecessary information about the ESP32 power handling #16
2024-02-11 Add WS2814 RGBW LED strip description
2024-02-19 Add shadcn button component
2024-02-19 Add esp32 to BOM #19
2024-02-19 Add ledstrip profile to BOM #19
2024-02-19 Add DC/DC converter to BOM #19
2024-02-19 added visualisation for multiple ledstrips
2024-02-25 placed leds in bars
2024-02-26 Add level shifter to BOM #19
2024-02-26 Add printplate to BOM #19
2024-02-26 Add cable box to BOM #19
2024-02-26 Update colorChange prop type in color-picker.vue #54
2024-02-26 Refactor colorChange prop to onChange #54
2024-02-26 Add color and onChange props to color-picker component #54
2024-02-26 Update number of LED-strips input range close #55
2024-02-26 Add border radius to led section close #56
2024-02-26 Add power supply to BOM #19
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2024-02-26 Add quantity and price to BOM #19
2024-02-26 Add size prop to color picker component close #59
2024-02-26 Make color picker props a const
2024-02-26 Add block terminal to BOM #19
2024-02-26 Fix price of Cable box #19
2024-02-26 Add led-effect component #41
2024-02-27 Update 24 to 5V converter
2024-02-27 Add subtle border around leds in home page
2024-02-27 Add fuse holder, auto fuse set, cables and female pin header set to Dom close #19
2024-02-28 Add LED pixel component #62
2024-02-28 Use LedPixel in homepage #62
2024-02-28 Add color validation for led-pixel component
2024-02-28 added backend call to get number of ledstrips available
2024-02-28 Add tooltip to LED pixel component
2024-02-29 Add copy to clipboard to led-pixel component close #63
2024-03-01 added wiring diagram to readme
2024-03-04 Fetch ledstrips simultaneously close #67
2024-03-04 Changed cables, fuse set in BOM #68
2024-03-04 Add timer that shows how long the fetchleds method took
2024-03-04 Set button text to copied when copying color hex close #73
2024-03-04 Fixed spelling mistake in BOM #68
2024-03-04 Add throttle method to utils
2024-03-04 Throttle color wheel onchange events #74
2024-03-04 Change power supply in BOM #68
2024-03-04 added pcb
    [Schematic.brd, Schematic.sch]
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2024-03-06 pcb verwijderd
    [Schematic.brd, Schematic.sch]
2024-03-11 Update searching ledstrips indicator
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2024-03-11 Update led-effect.vue component to include button variant
2024-03-11 Add onClick prop to led-effect component
2024-03-11 Cache ledstrip amount in server
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2024-03-11 changed led strip online status
2024-03-11 Update /leds response type
2024-03-18 Dynamically make sections in ledstrip
2024-03-18 Add LEDState schema and update paths in swagger.yaml
2024-03-18 added led array + get effect list
2024-03-18 Add tooltipText property to led-effect
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2024-03-18 Add tooltip-text prop to LedEffect component
2024-03-25 Refactor LED strip segment structure in swagger.yaml
2024-03-25 Add example values for LED strip index and segments
2024-03-25 fixed db connection + update swagger
    [swagger.yaml]
2024-03-25 Add ledstrips.js and refactor mqtt.js
2024-03-25 Refactor getLeds function to use ledstrips module
2024-03-25 Update color property to use getHex() method in leds.js
2024-03-25 Update Swagger schema for LEDState to include Ledstrip and Segment
2024-03-25 Update Ledstrip and Segment schemas in swagger.yaml
2024-03-25 Add POST endpoint for changing LED-strip configuration
2024-03-25 Add POST endpoint for LEDs
2024-03-25 Update LED strip rendering
2024-03-25 Fix duplicate ledstrips bug
2024-03-30 Update LED fetch interval
2024-03-30 Remove offline ledstrips from searchLeds function close #97
2024-03-31 Refactor LED-strip display in HomeView.vue
2024-04-02 Add Backend README.md with Virtual Ledstrip class diagram
2024-04-03 Add Virtual Ledstrip class documentation
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2024-04-15 Refactor effect.js to use ledstrips module
2024-04-15 fixed ledstrip effects
2024-04-22 Refactor updateColor method call in leds.js
2024-04-22 Sort ledstrips by index in ledstrips.js
2024-04-23 Add effect property to segment in leds.js close #128
2024-04-23 Add effect property to led-pixel.vue component #127
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2024-04-24 Fixed links in BOM
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2024-04-29 Add dark mode button
2024-04-29 Change darkmode button variant close #150
2024-04-30 Add Input and Button components close #152
2024-04-30 Add new LED strip component #154
2024-04-30 Fix selectedSegments prop type in led-strip.vue #154
2024-04-30 Use the new led-strip component to render ledstrips #154
2024-04-30 Update led-strip component to include 'All' button for selecting all segments #119
2024-04-30 Update led-strip component to fix effect selection bug close #156
2024-05-04 Reset selected segments when splitting a ledstrip close #159
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2024-05-13 Reverse order of ledstrip segments #177
2024-05-13 Fix type bug in leds.js close #185
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2024-05-14 Update README.md with Virtual Ledstrip documentation and UML diagram
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2024-05-19 Add tooltips to header buttons close #188 #202
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2024-11-18 fixed module error
    [SM-T580-Wandhalter_v2.3mf]
2025-02-20 Updated 3D Files
    [SamsungTabA6.3mf, SamsungTabA6.stl, SamsungTabA6Deksel.stl]
